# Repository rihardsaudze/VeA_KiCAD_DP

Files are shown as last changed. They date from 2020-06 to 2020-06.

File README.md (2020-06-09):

# VeA_KiCAD_R4

**ENG:** This is the main repository for my course work project in PCB design.  
Main objective of this course work is to create an Arduino Uno R3 clone/version, that is adjusted and modified for my own needs.

**LAT:** Šī ir mana projekta galvenā repozitorija, kurā tiks veidots kursa darbs "Datorizētā iespiedplašu projektēšanā"  
Kursa darba laikā plānots izveidot Arduino Uno R3 klonu/versiju, pielāgotu un pārveidotu savām vajadzībām.

***Author/Autors:*** *Rihards*

**Progress:**  
-15.05.2020 pabeigta principiālā shēma (finished schematic)  
-27.05.2020 pabeigts PCB dizains (finished PCB design)  
-09.06.2020 izveidoti GERBER un drill faili (generated GBR and DRL files)

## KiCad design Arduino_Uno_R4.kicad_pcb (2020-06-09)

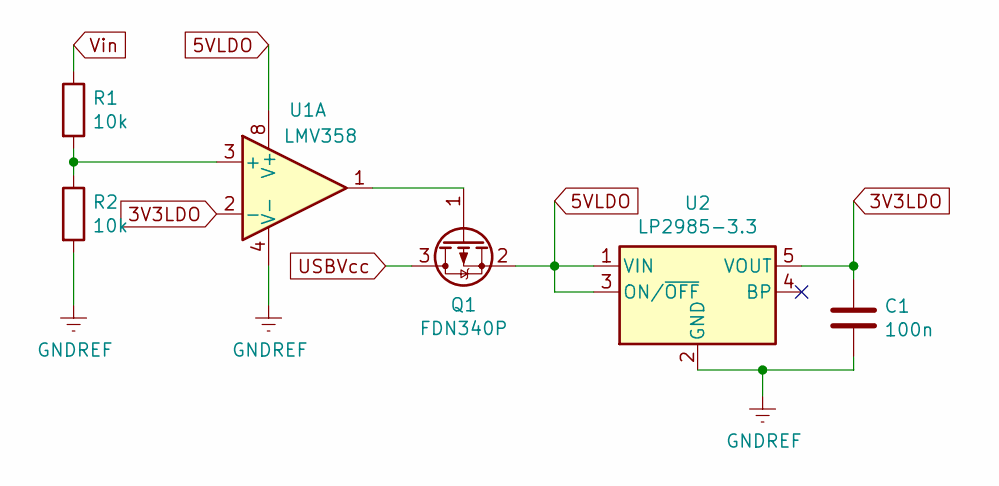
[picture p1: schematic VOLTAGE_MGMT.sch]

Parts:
C1: 100n; C_0603_1608Metric
Q1: FDN340P; SOT-23
R1, R2: 10k; R_0603_1608Metric
U1: LMV358; MSOP-8_3x3mm_P0.65mm
U2: LP2985-3.3; SOT-23-5

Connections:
3V3LDO: C1.1, U1.2 (-), U2.5 (VOUT); also elsewhere on the board
5VLDO: Q1.2 (S), U1.8 (V+), U2.1 (VIN), U2.3 (ON/~OFF~); also elsewhere on the board
unnamed: Q1.1 (G), U1.1
unnamed: R1.2, R2.1, U1.3 (+)
USBVcc: Q1.3 (D); also elsewhere on the board
USB_GND: C1.2, R2.2, U1.4 (V-), U2.2 (GND); also elsewhere on the board
Vin: R1.1; also elsewhere on the board

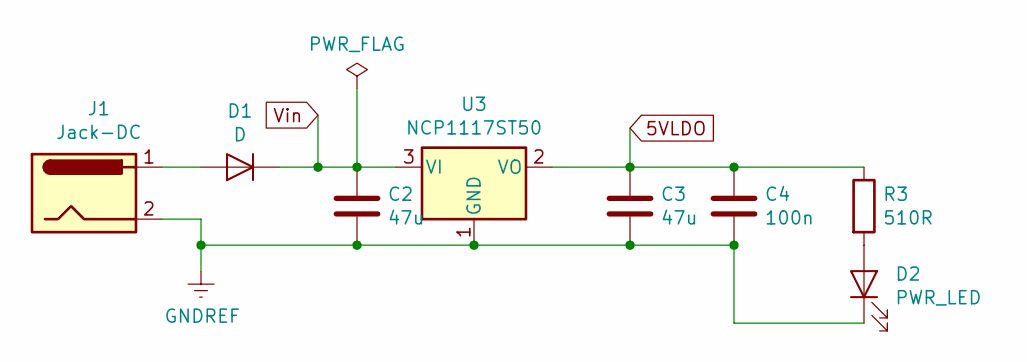
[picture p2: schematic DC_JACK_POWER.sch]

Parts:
C2, C3: 47u; C_0805_2012Metric
C4: 100n; C_0603_1608Metric
D1: D; D_SMF
D2: PWR_LED; LED_0603_1608Metric
J1: Jack-DC; DC_Jack
R3: 510R; R_0603_1608Metric
U3: NCP1117ST50; SOT-223-3_TabPin2

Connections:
5VLDO: C3.1, C4.1, R3.1, U3.2 (VO); also elsewhere on the board
unnamed: D1.2 (A), J1.1
unnamed: D2.2 (A), R3.2
USB_GND: C2.2, C3.2, C4.2, D2.1 (K), J1.2, U3.1 (GND); also elsewhere on the board
Vin: C2.1, D1.1 (K), U3.3 (VI); also elsewhere on the board

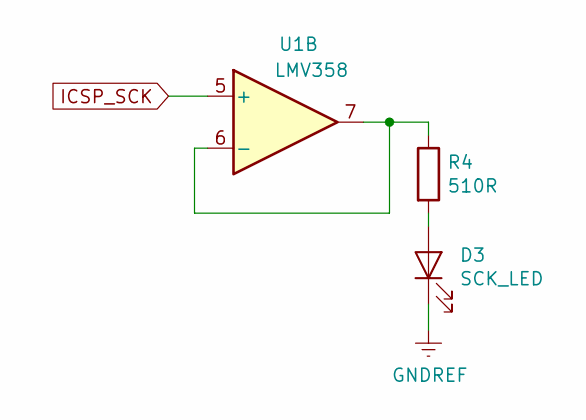
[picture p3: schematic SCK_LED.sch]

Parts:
D3: SCK_LED; LED_0603_1608Metric
R4: 510R; R_0603_1608Metric
U1: LMV358; MSOP-8_3x3mm_P0.65mm

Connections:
ICSP_SCK: U1.5 (+); also elsewhere on the board
unnamed: D3.2 (A), R4.2
unnamed: R4.1, U1.6 (-), U1.7
USB_GND: D3.1 (K); also elsewhere on the board

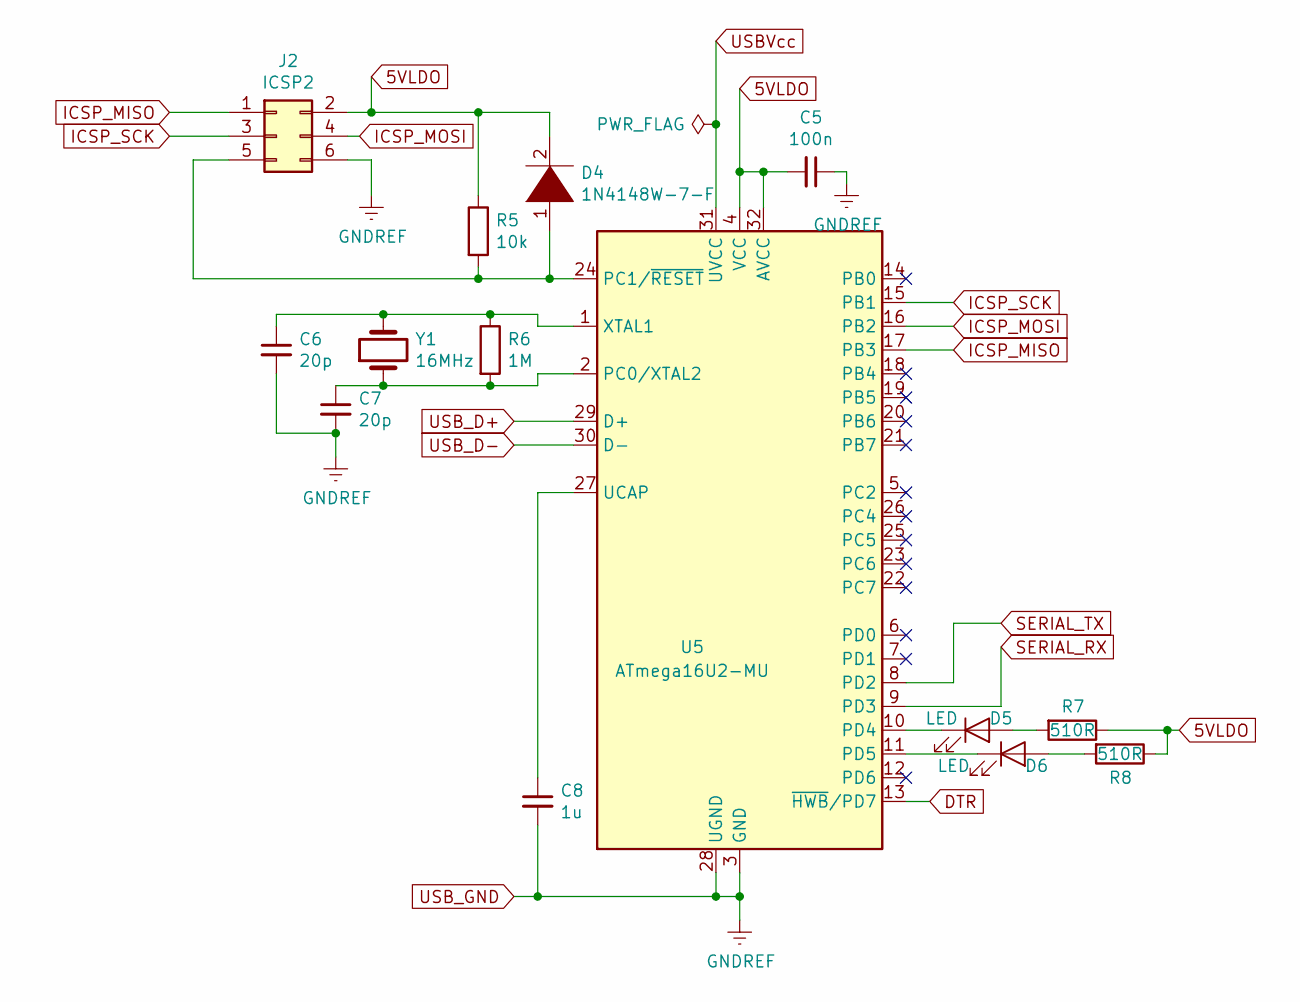
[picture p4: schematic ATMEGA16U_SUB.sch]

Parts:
C5: 100n; C_0603_1608Metric
C6, C7: 20p; C_0603_1608Metric
C8: 1u; C_0603_1608Metric
D4: 1N4148W-7-F; D_SOD-123
D5, D6: LED; D_0603_1608Metric
J2: ICSP2; PinHeader_2x03_P2.54mm_Vertical
R5: 10k; R_0603_1608Metric
R6: 1M; R_0603_1608Metric
R7, R8: 510R; R_0603_1608Metric
U5: ATmega16U2-MU; QFN-32-1EP_5x5mm_P0.5mm_EP3.1x3.1mm
Y1: 16MHz; HC-49S

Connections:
5VLDO: C5.2, D4.2 (A), J2.2, R5.1, R7.1, R8.1, U5.4 (VCC), U5.32 (AVCC); also elsewhere on the board
DTR: U5.13 (~HWB~/PD7); also elsewhere on the board
ICSP_MISO: J2.1, U5.17 (PB3)
ICSP_MOSI: J2.4, U5.16 (PB2)
ICSP_SCK: J2.3, U5.15 (PB1); also elsewhere on the board
unnamed: C6.1, R6.1, U5.1 (XTAL1), Y1.2
unnamed: C7.1, R6.2, U5.2 (PC0/XTAL2), Y1.1
unnamed: C8.1, U5.27 (UCAP)
unnamed: D4.1 (K), J2.5, R5.2, U5.24 (PC1/~RESET)
unnamed: D5.1 (K), U5.10 (PD4)
unnamed: D5.2 (A), R7.2
unnamed: D6.1 (K), U5.11 (PD5)
unnamed: D6.2 (A), R8.2
SERIAL_RX: U5.9 (PD3); also elsewhere on the board
SERIAL_TX: U5.8 (PD2); also elsewhere on the board
USBVcc: U5.31 (UVCC); also elsewhere on the board
USB_D+: U5.29 (D+); also elsewhere on the board
USB_D-: U5.30 (D-); also elsewhere on the board
USB_GND: C5.1, C6.2, C7.2, C8.2, J2.6, U5.3 (GND), U5.28 (UGND), U5.33 (GND); also elsewhere on the board

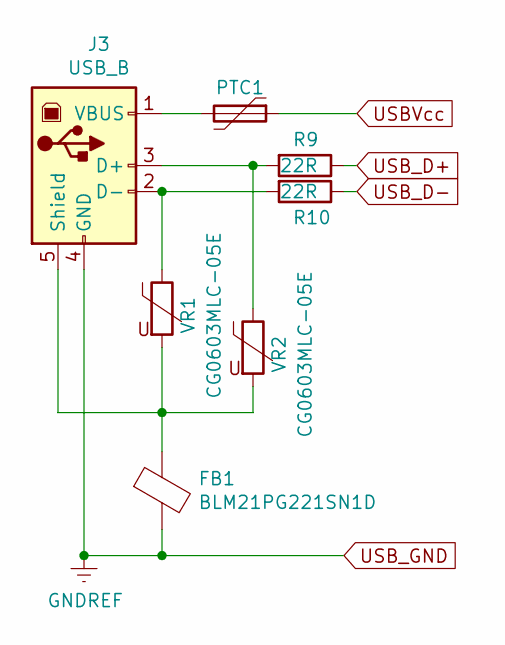
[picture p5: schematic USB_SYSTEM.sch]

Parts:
FB1: BLM21PG221SN1D; C_0805_2012Metric
J3: USB_B; USB_B_OST_USB-B1HSxx_Horizontal
PTC1: MF-MSMF-050-2; Fuse_1812_4532Metric
R9, R10: 22R; R_0603_1608Metric
VR1, VR2: CG0603MLC-05E; C_0603_1608Metric

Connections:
unnamed: FB1.1, J3.5 (Shield), VR1.2, VR2.2
unnamed: J3.1 (VBUS), PTC1.2
unnamed: J3.2 (D-), R10.2, VR1.1
unnamed: J3.3 (D+), R9.2, VR2.1
USBVcc: PTC1.1; also elsewhere on the board
USB_D+: R9.1; also elsewhere on the board
USB_D-: R10.1; also elsewhere on the board
USB_GND: FB1.2, J3.4 (GND); also elsewhere on the board

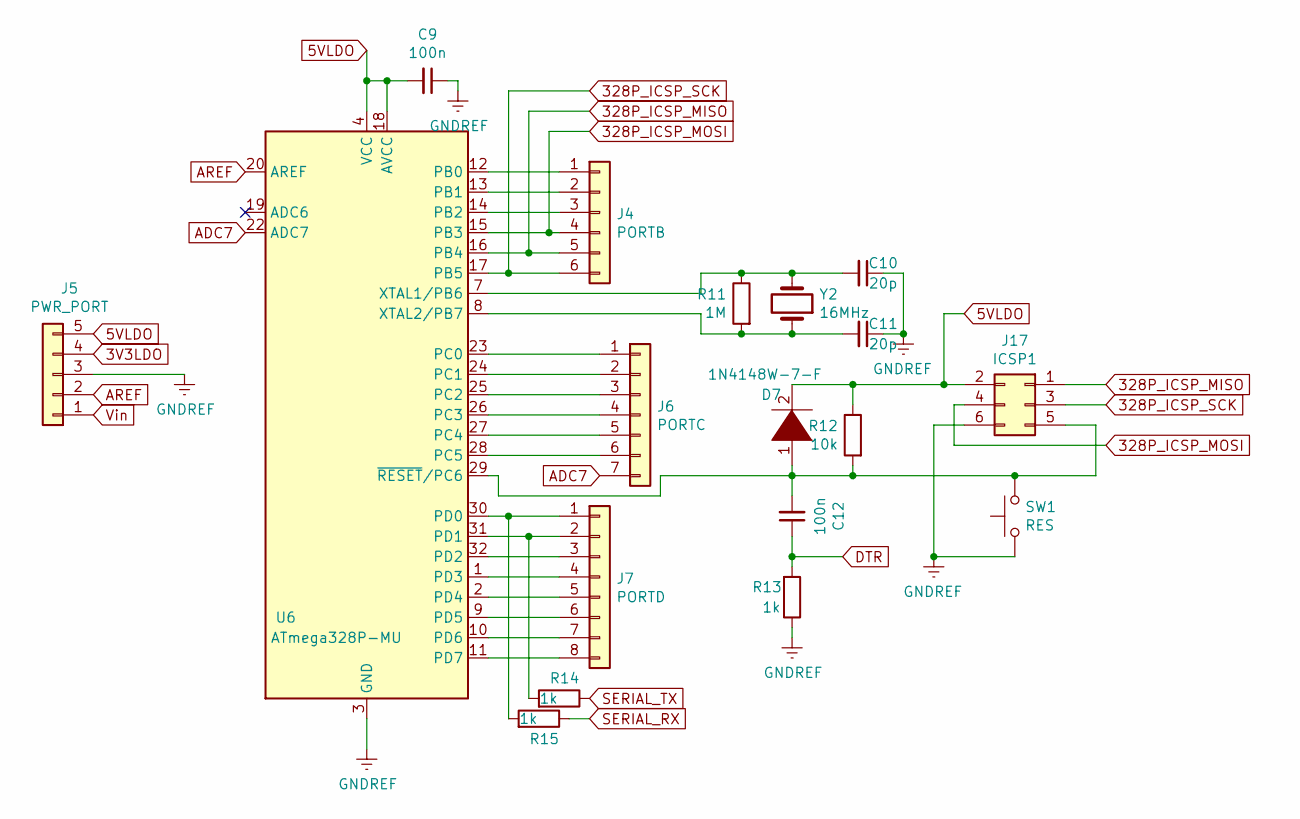
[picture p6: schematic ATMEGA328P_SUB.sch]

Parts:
C9, C12: 100n; C_0603_1608Metric
C10, C11: 20p; C_0603_1608Metric
D7: 1N4148W-7-F; D_SOD-123
J4: PORTB; PinHeader_1x06_P2.54mm_Vertical
J5: PWR_PORT; PinHeader_1x05_P2.54mm_Vertical
J6: PORTC; PinHeader_1x07_P2.54mm_Vertical
J7: PORTD; PinHeader_1x08_P2.54mm_Vertical
J17: ICSP1; PinHeader_2x03_P2.54mm_Vertical
R11: 1M; R_0603_1608Metric
R12: 10k; R_0603_1608Metric
R13, R14, R15: 1k; R_0603_1608Metric
SW1: RES; SW_SPST_EVQP2
U6: ATmega328P-MU; QFN-32-1EP_5x5mm_P0.5mm_EP3.1x3.1mm
Y2: 16MHz; HC-49S

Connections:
3V3LDO: J5.4; also elsewhere on the board
5VLDO: C9.2, D7.2 (A), J5.5, J17.2, R12.1, U6.4 (VCC), U6.6 (VCC), U6.18 (AVCC); also elsewhere on the board
328P_ICSP_MISO: J4.5, J17.1, U6.16 (PB4)
328P_ICSP_MOSI: J4.4, J17.4, U6.15 (PB3)
328P_ICSP_SCK: J4.6, J17.3, U6.17 (PB5)
ADC7: J6.7, U6.22 (ADC7)
AREF: J5.2, U6.20 (AREF)
DTR: C12.1, R13.2; also elsewhere on the board
unnamed: C10.2, R11.1, U6.7 (XTAL1/PB6), Y2.2
unnamed: C11.2, R11.2, U6.8 (XTAL2/PB7), Y2.1
unnamed: C12.2, D7.1 (K), J17.5, R12.2, SW1.2, U6.29 (~RESET~/PC6)
unnamed: J4.1, U6.12 (PB0)
unnamed: J4.2, U6.13 (PB1)
unnamed: J4.3, U6.14 (PB2)
unnamed: J6.1, U6.23 (PC0)
unnamed: J6.2, U6.24 (PC1)
unnamed: J6.3, U6.25 (PC2)
unnamed: J6.4, U6.26 (PC3)
unnamed: J6.5, U6.27 (PC4)
unnamed: J6.6, U6.28 (PC5)
unnamed: J7.1, R15.2, U6.30 (PD0)
unnamed: J7.2, R14.2, U6.31 (PD1)
unnamed: J7.3, U6.32 (PD2)
unnamed: J7.4, U6.1 (PD3)
unnamed: J7.5, U6.2 (PD4)
unnamed: J7.6, U6.9 (PD5)
unnamed: J7.7, U6.10 (PD6)
unnamed: J7.8, U6.11 (PD7)
SERIAL_RX: R15.1; also elsewhere on the board
SERIAL_TX: R14.1; also elsewhere on the board
USB_GND: C9.1, C10.1, C11.1, J5.3, J17.6, R13.1, SW1.1, U6.3 (GND), U6.5 (GND), U6.21 (GND), U6.33 (GND); also elsewhere on the board
Vin: J5.1; also elsewhere on the board

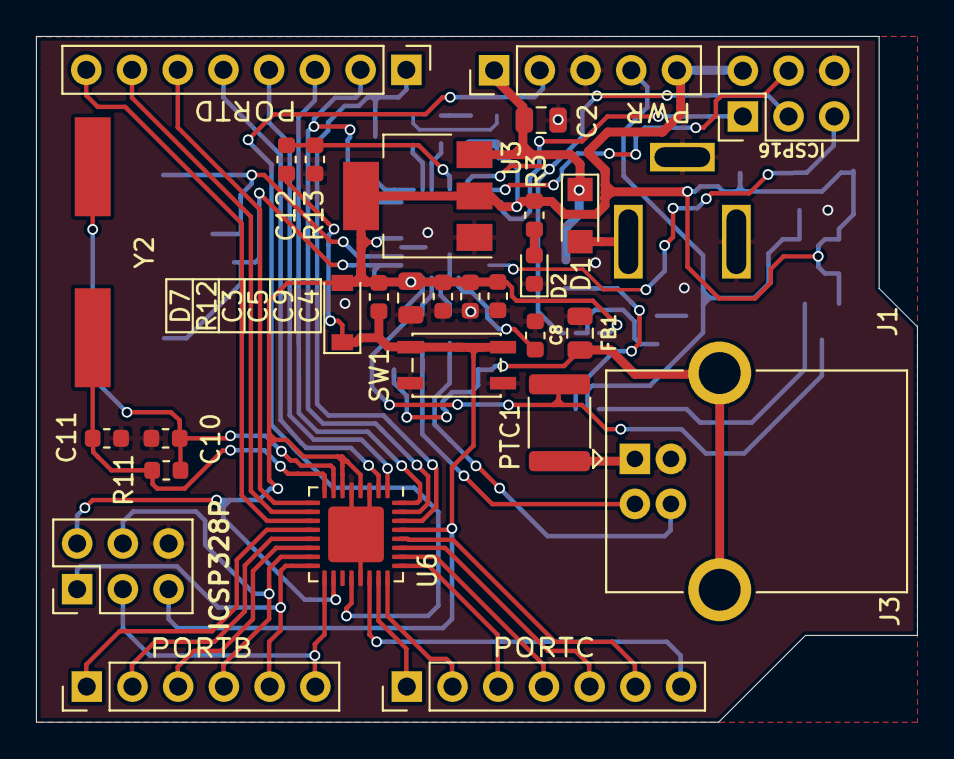
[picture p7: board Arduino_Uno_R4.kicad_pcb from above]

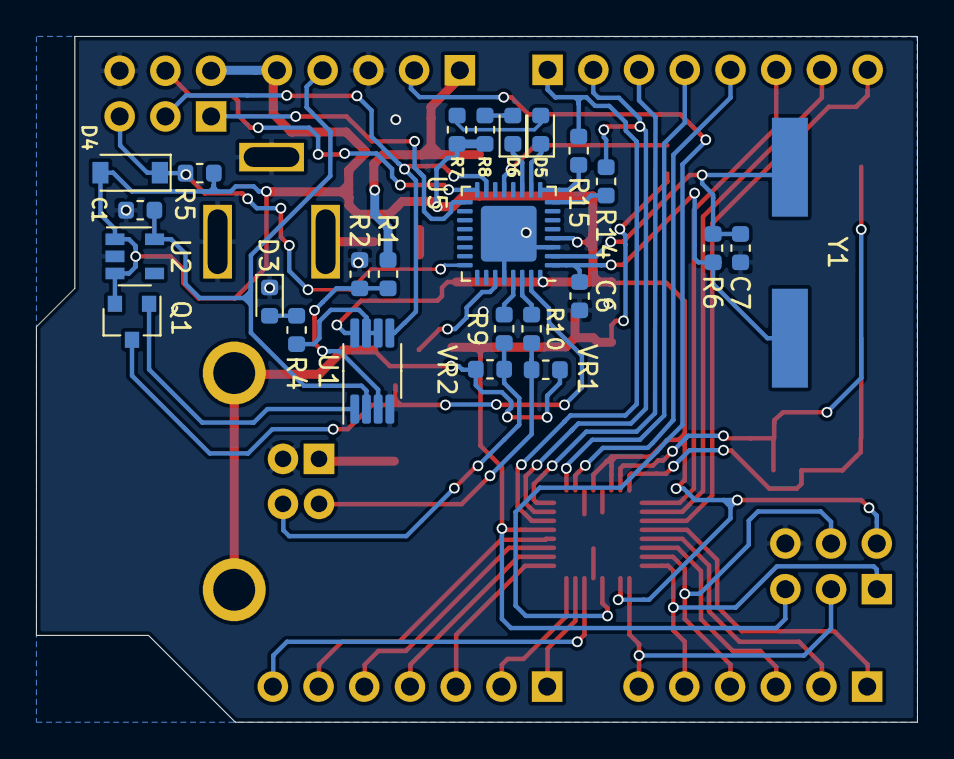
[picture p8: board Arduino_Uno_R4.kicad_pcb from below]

Board: 2 copper layers, 48.9 x 38.1 mm, 55 parts (25 on the bottom side), 56 nets.

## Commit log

2020-05-15 Cleaned up and finished schematic
    [ATMEGA16U_SUB.sch, ATMEGA328P_SUB.sch, Arduino_Uno_R4.kicad_pcb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]
2020-05-20 Set component footprints, added datasheets, fixed the last DRC error and a couple component values
    [ATMEGA16U_SUB.sch, ATMEGA328P_SUB.sch, DC_JACK_POWER.sch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]
2020-05-24 Updated the schematic, added missing footprints, started PCB design
    [ATMEGA16U_SUB.sch, ATMEGA328P_SUB.sch, DC_JACK_POWER.sch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]
2020-05-24 Improved readability, fixed component reference positions, added text for IO ports
    [Arduino_Uno_R4.kicad_pcb]
2020-05-27 Improved consistency of component label positioning, added a couple descriptive labels
    [Arduino_Uno_R4.kicad_pcb]
2020-06-09 Generated GERBER and drill files
    [Arduino_Uno_R4-B_Cu.gbr, Arduino_Uno_R4-B_Mask.gbr, Arduino_Uno_R4-B_SilkS.gbr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]
